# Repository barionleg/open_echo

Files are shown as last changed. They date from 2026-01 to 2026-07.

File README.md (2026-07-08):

links uPpdated by [barionleg](https://github.com/barionleg/) @20260708, to make them viewble online 

Open Echo Cover

## Universal Open-Source SONAR Controller and Development Stack

An ongoing open-source hardware and software project for building sonar systems for testing, boating, bathymetry, and research.  
The most commonly used hardware is the [TUSS4470 Arduino Shield](https://github.com/barionleg/open_echo/TUSS4470_shield_002/), which stacks on top of an Arduino Uno to drive the TUSS4470 ultrasonic driver.  
The board can run the [RAW Data Firmware](https://github.com/barionleg/open_echo/TUSS4470_shield_002/getting_started_TUSS4470_firmware.md) to operate a wide variety of ultrasonic transducers, covering frequencies from 40 kHz up to 1000 kHz in different media such as air or water.  

The [NMEA Output Firmware](https://github.com/barionleg/open_echo/TUSS4470_shield_002/arduino/NMEA_DBT_OUT/NMEA_DBT_OUT.ino) can read depth data from commercially available in-water ultrasonic transducers (e.g., on boats) and output NMEA0183-compatible data to a computer or a UART-connected device such as a Pixhawk or other controllers.  

Open Echo has been tested on multiple ultrasonic transducers and is compatible with all of them—from car parking sensors to Lowrance Tripleshot side-scan transducers.  

The [Python Interface Software](https://github.com/barionleg/open_echo/TUSS4470_shield_002/getting_started_interface.md) connects to Open Echo boards running the [RAW Data Firmware](https://github.com/barionleg/open_echo/TUSS4470_shield_002/getting_started_TUSS4470_firmware.md). It can display raw echo data, change configurations, output a TCP depth data stream, and more.  

Check the [Getting Started Guide](https://github.com/barionleg/open_echo/TUSS4470_shield_002/README.md)!  

If something is unclear or you find a bug, please open an issue.  

Raw Data Waterfall chart in the Python Desktop software:  
Open Echo Interface Software

## Getting the Hardware

If you need the hardware, you can order it using the [Hardware Files](https://github.com/barionleg/open_echo/TUSS4470_shield_002/TUSS4470_shield_hardware/TUSS4470_shield) from a board + SMT house ([JLC recommended](https://jlcpcb.com/?from=Neumi)).

They can also be bought as a complete and tested set direclty from Elecrow: https://www.elecrow.com/open-echo-tuss4470-development-shield.html

If they’re out of stock, or if you’d prefer to order them within Germany to reduce shipping costs, please send me an email at: openechoes@gmail.com

All profits go directly toward supporting and advancing the Open Echo project!

<b>If you don't order the boards directly from me or Elecrow, please be aware that I can't provide support.</b>

[TUSS4470 Arduino Shield](https://github.com/barionleg/open_echo/TUSS4470_shield_002/):  
PCB overview TUSS4470

### This project is currently in development. The [TUSS4470 Development Shield](TUSS4470_shield_002/) is ready for external use!  
Development is ongoing! Check the documentation and Discord channel for the latest updates.  

Want to stay updated or participate? Join the [Discord](https://discord.com/invite/rerCyqAcrw)!  

Check the [Getting Started Guide](https://github.com/barionleg/open_echo/TUSS4470_shield_002/README.md).  

## Vision
An accessible Open Source SONAR stack for development, research and real use:
- Open Source SONAR technology for differernt use cases
- support for a variety of commercial or DIY transducers in water and air
- relatively simple hardware that can be ordered from a board house
- easy entry for less experienced users
- community for exchange and development
- development of more advanced SONAR applications

--------
## Current State
- Universal TUSS4470-based Arduino shield for testing ultrasonic transducers  
- Python interface software for raw data visualization, configuration, and TCP data output  
- Tested depth range of at least 50 m in water  
- NMEA0183 compatible (DBT data output to other devices)  
- New all-in-one boards with STM32, TUSS4470, and boost converter currently in development
- picoW implementation in development (already successfull)
- UDP network RAW data transfer from picoW to Python interface running

--------
## Progress

The new (May 2025) [TUSS4470 Arduino Shield](https://github.com/barionleg/open_echo/TUSS4470_shield_002/) supports transducers from 40 kHz to 1000 kHz. It can drive them, receive echoes, filter signals, and send raw echo data to the Python backend.  
Driver voltage can be supplied from Arduino VIN or via the external XT30 connector. With an MT3608 boost converter, USB can be used as a power supply and boosted to the desired drive voltage (manual soldering required).  

The [TUSS4470 Arduino Shield](https://github.com/barionleg/open_echo/TUSS4470_shield_002/) is and will remain the main development board for this project. It is an excellent platform for testing and development.  
It can drive a wide range of transducers at different voltages, but it is limited by RAM size and sampling speed. You can capture 1800 samples at 12 microseconds per sample (~18 m range in water) with 8-bit resolution. For longer ranges, you can add a delay to capture echoes from more distant objects.  
This makes it a perfect board for learning, testing, and prototyping. Most software development is done using this board.  

For special use cases, additional boards and software are under development. 
Check the [development](https://github.com/barionleg/open_echo/development) folder for development work.

--------
## Open Echo Interface Software

Firmware examples are available in each project folder.  
The [**Open Echo Interface Software**](https://github.com/barionleg/open_echo/TUSS4470_shield_002/echo_interface.py) allows you to control Open Echo boards, view live data, and adjust board settings.  

Live echogram in water on Python software (6x speed):  
Software running with live echo data

## Test results Baltic Sea
Tested using a built-in 150 kHz SEAFARER transducer, powered at 15-20 V via an MT3608 boost converter from USB. In the plots, data capture begins at the bottom.

<table>
  <tr>
    <td align="center">
      38m Range<br/>
      <sub><b>38 m range test</b></sub>
    </td>
    <td align="center">
      Kiel Channel<br/>
      <sub><b>Kiel Channel sand and mud</b></sub>
    </td>
    <td align="center">
      Stollergrund<br/>
      <sub><b>Slope near Stollergrund</b></sub>
    </td>
  </tr>
  <tr>
    <td align="center">
      Stones and Sand<br/>
      <sub><b>Stones and sandy seabed</b></sub>
    </td>
    <td align="center">
      Fish<br/>
      <sub><b>Fish detection</b></sub>
    </td>
    <td align="center">
      Multiple Reflections<br/>
      <sub><b>Multiple reflections and seaweed</b></sub>
    </td>
  </tr>
  
</table>

## Videos

LINK TO LATEST VIDEO (https://www.youtube.com/watch?v=XF7rNGt6UYA)

https://www.youtube.com/watch?v=R3_NO2F7PsI  
https://www.youtube.com/watch?v=msbLVsY8xhQ  
https://www.youtube.com/watch?v=eJ8jVEQSx_Y  
https://www.youtube.com/watch?v=Bxh3rWd5RZk  
https://www.youtube.com/watch?v=UDYWQIizN7A  

## Useful Links
https://www.rapp-instruments.de/RemoteSensing/Roves/sidescan/sidescan.htm  
https://www.youtube.com/watch?v=ZtUkt8Q4EJE  

## Transducers: 

| Transducer Name | Ranking | Description | Frequency | Range Air/Water |  Price | Link |
|---|---|---|---|---|---|---|
| NASA / Seafarer 150kHz Echo Sounder | ⭐ ⭐ ⭐ | NASA in-hull boat transducer for echo sounding and simple fish-finding | 150kHz | >2m/>50m | 50-100€ | https://www.nasamarine.com/product/depth-transducer-with-7-metre-cable/7 
| Raymarine CPT-S |  ⭐ ⭐ ⭐ | High quality In-hull transducer with two frequencies | 50 + 200kHz | 2m/>50m | 200€ | https://www.raymarine.com/de-de/unsere-produkte/fischfinder-und-sonarmodule/fischfindergeber/cpt-s-durchbruchgeber |
| Lowrance Tripleshot Sidescan | ⭐ ⭐ ⭐ | Sidescan transducer with three FANS + temperature + down-scan | 200 + 455 + 600kHz | 0m/>20m | 200€ | https://www.echolotzentrum.de/shop/lowrance-tripleshot-heckgeber/ |
| Cheap Bathymetry 200kHz | ⭐ ⭐ ⭐ | good range, good price/performance, hard to order | 200kHz | 2m/>30m | 25€ | https://www.alibaba.com/product-detail/Range-customization-lakes-river-surveys-no_1600829423846.html |
| Cheap Car Parking Sensor | ⭐ ⭐ | Great for air, also works in water (not recommended) | 40kHz | >7m/>30m | 5€ | https://de.aliexpress.com/item/1005006546490802.html |
| Water flow sensor transducer | ⭐ ⭐ | Cheap and works in Air and Water. Very narrow beam in Water (about 5°)! | 1000kHz | 0.25m/>10m | 16€ for 5pcs | https://de.aliexpress.com/item/32818381566.html |
| Only for air 200 kHz | ⭐ | has a sinter glass matching layer, should only be used in air | 200kHz | 0.8m/(>8m) | 10€ | https://de.aliexpress.com/item/1005006007865920.html |
| Different Encapsualated Transducers | ⭐| Can be used for short range testing at higher frequencies | 200,300,400kHz | ?m/?m | 9-18€ | https://de.aliexpress.com/item/4000389134890.html |
| Very small PZT only | ⭐ | Only for testing / experimentation | 200kHz | 0.2m/?m | 10€ | https://de.aliexpress.com/item/1005007032482539.html |

> [!Note]
> The range values were measured using the TUSS4470 shield and Arduino Uno with an MT3608 boost converter set to 20 V for vDRV, so consider them approximate.

> [!Tip]
> As a general rule of thumb, lower frequencies propagate farther, while higher frequencies produce narrower beams and more detailed echoes.
>
> If you need a transducer for bathymetry, choose one of the first four options. Most commercial marine-grade (boating) transducers are also suitable, as long as they operate in the 40-1000 kHz range.

# Big Thanks for Your Support!
www.kogger.tech

## to the awesome project contributors:
Check this Cheap Yellow Display implementation out: https://github.com/matztam/open_echo_cyd_display
  
And all the great stuff JohnCHarrington contributed: https://github.com/JohnCHarrington/open_echo

## Star History

Star History Chart (https://www.star-history.com/#Neumi/open_echo&type=date&legend=top-left)

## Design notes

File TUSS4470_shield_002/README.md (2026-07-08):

# Open Echo TUSS4470 Shield Getting Started Guide

The TUSS4470 is an ultrasonic driver and receiver IC designed for seamless interaction with ultrasonic transducers. The TUSS4470 Arduino Shield is a development board that enables quick evaluation of the TUSS4470's features using the Arduino UNO platform.

### Overview
This repository provides a quick-start guide and example Arduino sketches for experimenting with Time-of-Flight (ToF) applications using the TUSS4470. The shield is ideal for development, testing, and prototyping, but is not intended as a finished consumer product.

### Getting Started
Connect the shield to an Arduino UNO.

Upload one of the provided example sketches to explore different features of the TUSS4470.

Use the Python software to see the echoes.

### Ordering
The shield can be easily ordered via [JLCPCB](https://jlcpcb.com/?from=Neumi) or other PCB fabrication services.

TUSS4470 schematic

> [!Note]
> I just got a few new boards, I sell as starter kits. Feel free to DM me on [Discord](https://discord.com/invite/rerCyqAcrw) if you're interested. Or send an email to: openechoes@gmail.com One assmebled board is 50€ + shipping. (10/2025)

PCB overview TUSS4470

## Electrical Connections
The TUSS4470 Shield is designed specifically for use with the Arduino UNO. It is not software- or pin-compatible with other Arduino boards at this time.

### Pin Connections
The shield interfaces with the Arduino UNO the following:
- SPI interface
- Four digital GPIOs
- Analog pin A0

### cINN and cFLT Filtering Capacitor Selection for Transducer Frequency
To support different ultrasonic transducers and their respective drive frequencies, the board provides preset capacitor options for <b/>40, 150, 200 (and 600) kHz</b>.

> [!Important]
> Use the onboard jumpers to select the appropriate cINN and cFLT values.

### Custom Capacitor Configuration
If you need to drive transducers at frequencies other than the provided presets and combinations (40 kHz, 150 kHz, 200 (and 600) kHz), you can customize the capacitor values:
- Desolder the default "CUSTOM" capacitors. (for cINN and cFLT)
- Solder your own calculated capacitor values onto the "CUSTOM" pads.

> [!TIP]
> Capacitors can be combined in parallel to achieve intermediate values.
> For example, to support 150 kHz, both the 200 kHz and CUSTOM capacitors are used in parallel to produce the required total capacitance.
> On board version 002, "Custom" is pre-selected to match the right capacitances <b/>together</b> with the 200kHz capacitors for 150kHz. 

Below is the electrical connection layout for the cINN and cFLT capacitors and jumpers:
TUSS4470 schematic

### Power Supply Options
The board supports two power input options:
- VIN (Arduino VIN pin):
Use this when the transducer operates at 12V max, as the Arduino cannot tolerate higher voltages.

- XT30 Connector:
Use this if you require higher voltage (up to 28V max) for more powerful transducers.

- MT3608 Boost Converter:
You can add an MT3608 boost converter to your board to generate a higher vDRV from the USB 5V supply. This solution is reliable and works well in many applications, such as powering marine transducers.
Simply take the MT3608 module (included in the starter kits), secure it to the shield with double-sided tape, and connect the three wires as shown:
TUSS4470 schematic

> [!Tip]
> To get started, use a 12V power supply. Many ultrasonic transducers operate reliably at this voltage.
> 
> Lower voltages may not adequately excite the transducer, resulting in weak or no echo signals.
> 
> The MT3608 should not be turned much further than 22V, as it becomes unstable.

> [!Warning]
> Do not exceed 28V input. Higher voltages can damage the board or components. Ensure proper polarity!

### Transducer Connection
Connect your PZT crystal or preassembled ultrasonic transducer to the "Transducer" header:

- Top pin: Ground (GND) / Shield
- Bottom pin: Signal

> [!Important]
> Proper polarity is crucial to minimize electrical noise and ensure optimal performance.
> For transducer connections exceeding 10 cm in length, use coaxial cable. Connect the cable shield to the transducer ground (GND).

The recommended setup is illustrated below:
TUSS4470 Board ready to use

> [!Important]
> Always connect GND/Shield to the TOP pin on the transducer.
> Using the wrong pin increases powerline noise and significantly weakens the signal.

Below: Comparison of a transducer wired incorrectly (left half) vs. correctly (right half).
Powerline noise on transducer cable shield

<b/>Next Steps: Proceed to [Getting Started with Arduino TUSS4470 Firmware](getting_started_TUSS4470_firmware.md).</b>

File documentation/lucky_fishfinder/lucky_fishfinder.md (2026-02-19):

---
layout: default
title: Lucky Fishfinder
nav_order: 9
---

# open_echo

Reverse engineering of the LUCKY fishfinder to learn about ultrasonics projects from a real product.

Using a trigger and analog pin on an Arduino UNO we can read RAW echo data from the LUCKY fishfinder product.

As of today, there are at least three hardware versions of the LUCKY fishfinder. All of them seem to follow a similar concept, but the pinout is different!

LUCKY fishfinder pins:
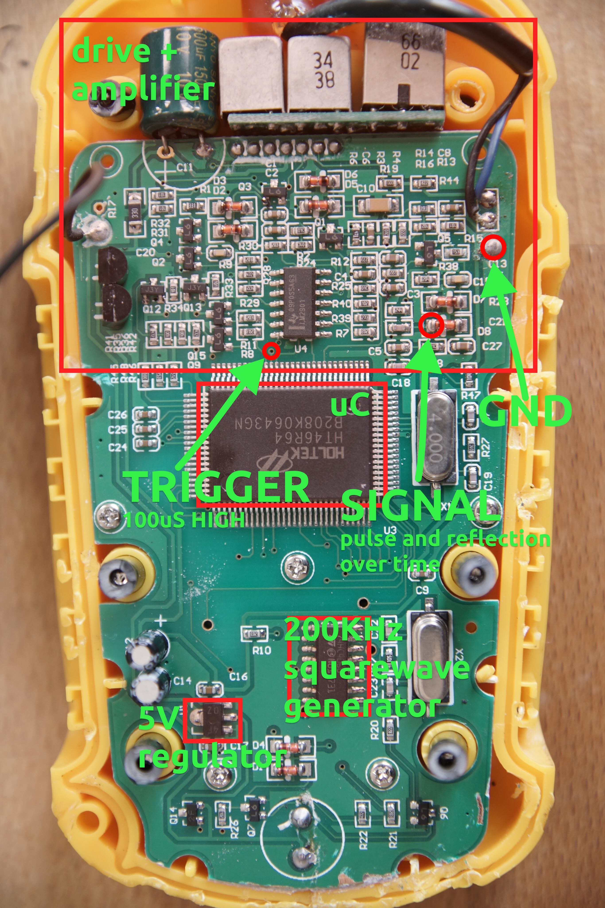
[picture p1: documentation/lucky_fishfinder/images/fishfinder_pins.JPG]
LUCKY fishfinder pin hack


Measured results using LUCKY fishfinder, FastLOGIC (Arduino) and Matplotlib + Python:
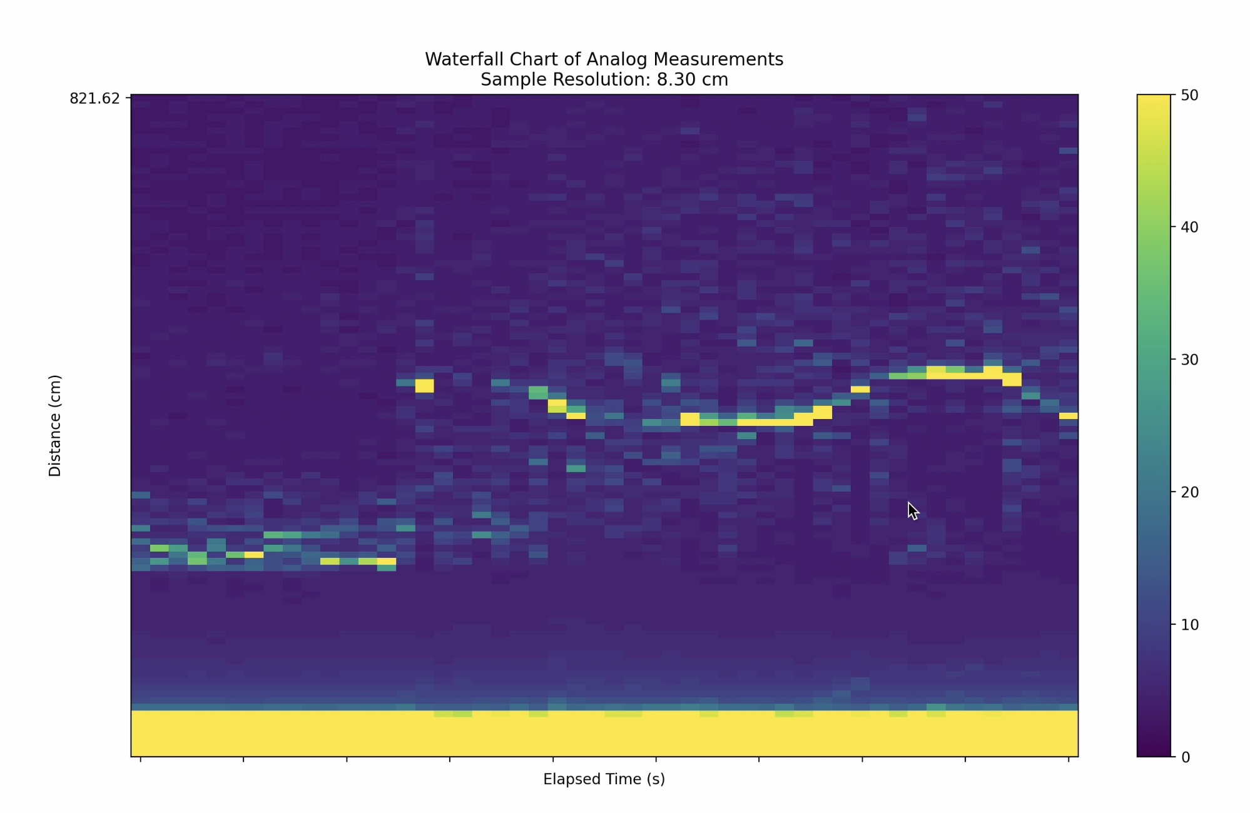
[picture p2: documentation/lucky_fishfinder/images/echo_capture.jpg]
LUCKY fishfinder pin hack


The chart shows a measurement of reflection time (translated to cm using 1482m/s speed of sound in water) and the past 50 measurements. The LUCKY fish finder takes around 2.3 full measurements per second. The brigter the pixel, the stronger the return signal. The plot shows the sandy ground in the first 1/4 and the rest is the reflection of a metal ladder in the water (horizontal).

# More info in this video:
LINK TO VIDEO (https://www.youtube.com/watch?v=UDYWQIizN7A)

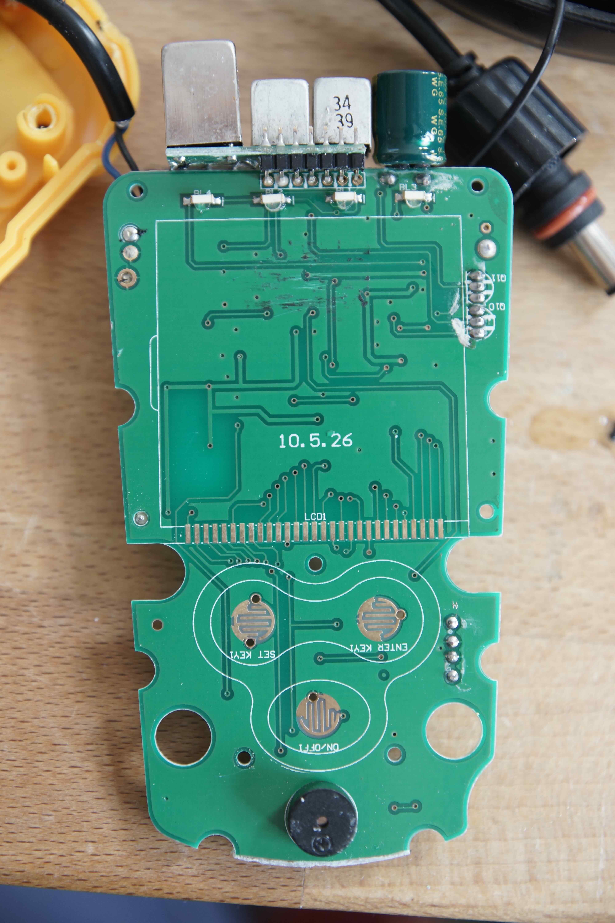
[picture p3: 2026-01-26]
documentation/lucky_fishfinder/images/back.JPG

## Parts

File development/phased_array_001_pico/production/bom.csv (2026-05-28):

Designator | Footprint | Quantity | Value | LCSC Part #
A1 | RaspberryPi_Pico_Common_Unspecified | 1 | RaspberryPi_Pico_W
C10, C11, C16, C17, C18, C19, C8, C9 | 0603 | 8 | 1uF | C15849
C12, C13, C14, C15 | 0603 | 4 | 100nF | C1525
C3 | 0603 | 1 | 10uF | C19702
J2 | PinHeader_1x03_P2.54mm_Vertical | 1 | OUT_SELECT
J3 | PinHeader_1x01_P2.54mm_Vertical | 1 | MT3608_OUT
J4 | PinHeader_1x01_P2.54mm_Vertical | 1 | MT3608_IN
J5, J6 | PinHeader_1x01_P2.54mm_Vertical | 2 | MT3608_GND
J7 | PinHeader_1x03_P2.54mm_Vertical | 1 | BOOST_ENABLE
MK1, MK2, MK3, MK4, MK5, MK6, MK7, MK8 | JST_EH_S2B-EH_1x02_P2.50mm_Horizontal | 8 | Microphone_Crystal
MK9 | JST_EH_S2B-EH_1x02_P2.50mm_Horizontal | 1 | Transducer_TX
Q1 | SOT-23 | 1 | MMBT2222A | C8512
R1, R10, R14, R18, R2, R22, R26, R30, R34, R6 | 0603 | 10 | 10k | C25804
R11, R12, R13, R15, R16, R5, R7, R8, R9 | 0603 | 9 | 1k | C21190
R17, R21, R25, R29, R33, R35, R36, R37 | 0603 | 8 | 100k | C25803
R19, R23, R27, R31, R38, R39, R40, R41 | 0603 | 8 | 1M | C22935
TP1 | TestPoint_Loop_D2.54mm_Drill1.5mm_Beaded | 1 | U_TRIGG
TP2 | TestPoint_Loop_D2.54mm_Drill1.5mm_Beaded | 1 | GND
U1, U3 | SOIC-14_3.9x8.7mm_P1.27mm | 2 | LM339 | C7948
U2, U5 | SOIC-14_3.9x8.7mm_P1.27mm | 2 | MCP6004 | C7378

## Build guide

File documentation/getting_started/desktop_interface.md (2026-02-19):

---
layout: default
title: Desktop Interface
parent: Getting Started
nav_order: 3
---

# Getting Started Open Echo Interface Software

The ***Open Echo Interface*** is a cross-platform Python application that interacts with the Arduino + TUSS4470 Shield. 
It displays ultrasonic echo data in real-time using a waterfall chart visualization. 
The application is intended primarily as a testing and development tool, but is stable enough for continuous use -tested for several days on a Raspberry Pi 4 without issues.

### Key Features
- Connects to Open Echo hardware over serial or UDP
- Displays real-time and historical data in a waterfall chart
- Auto-gain to adjust the waterfall chart colors
- Shows detected depth, and (if supported) temperature and drive voltage (`vDRV`)

> **Note**  
> This interface is primarily intended for development and testing. It's proven stable, but not yet a polished end-user application.

---

## Installation & Setup

### 1. Install openecho
```bash
pip install open-echo
```

### 2. Start Open Echo Interface Software
Run the following command to start the web server. 
```bash
openecho desktop
```

Select the correct COM port, then click Connect or press c on your keyboard. Once connected, the Open Echo board will begin streaming data, which will appear on the right side of the interface.
The red horizontal line indicates the currently detected depth, based on the strongest first echo received after the ring-down delay.

Open Echo Interface Software

### 4. Change to your own needs

You can change different settings in the first lines of the [**Open Echo Interface**](https://github.com/neumi/open_echo/tree/main/python/src/open_echo/desktop.py) code to customize it to your specific use cases.

### 📊 Parameter Settings

| Parameter | Description |
|---|---|
| `BAUD_RATE` | Must match the baud rate configured in the Arduino firmware. |
| `NUM_SAMPLES` | Must match the `NUM_SAMPLES` value used in the Arduino firmware. Can be overriden in the interface settings |
| `MAX_ROWS` | Sets the number of historical measurements displayed in the chart before it scrolls. |
| `Y_LABEL_DISTANCE`| Defines the vertical axis label spacing, in centimeters. |
| `SPEED_OF_SOUND`  | Used to convert sample timing into distance. Set to ~330 for air, ~1450 for water. Can be overriden in the interface settings|
| `SAMPLE_TIME` | Sampling interval in microseconds. For the Arduino UNO with [TUSS4470_arduino.ino](arduino/TUSS4470_arduino/TUSS4470_arduino.ino), this must be set to **13.2 µs**. Can be overriden in the interface settings|

--- 
Want to stay updated, have questions or want to participate? Join my [Discord](https://discord.com/invite/rerCyqAcrw)!

Or write an issue. Thanks!

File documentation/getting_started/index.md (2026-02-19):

---
layout: default
title: Getting Started
has_children: true
nav_order: 1
---

Getting started guides for Open Echo.

First, you will need an [Open Echo TUSS4470 Arduino Shield](TUSS4470_hardware.md).

This repository provides two software components to support the TUSS4470 Arduino Shield:
- [Arduino Firmware](TUSS4470_firmware.md) - Runs on an Arduino UNO board with the TUSS4470 shield and handles signal generation, echo capture, and communication.
- [Open Echo Interface](desktop_interface.md) - A desktop application that communicates with the Arduino, displays echo data as a real-time waterfall chart, and will soon allow runtime configuration of the system.

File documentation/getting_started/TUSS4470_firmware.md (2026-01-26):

---
layout: default
title: TUSS4470 Firmware
parent: Getting Started
nav_order: 2
---

# Getting Started with Arduino TUSS4470 Firmware

## Arduino Firmware
The Arduino firmware initializes the TUSS4470 device and manages the ultrasonic signal transmission and echo reception cycle. It sends digitized echo data over the serial interface to a host computer for analysis.

**Key Features**
- SPI communication with TUSS4470 chip
- Configurable drive frequency
- Adjustable sampling size (defines detection range)
- Basic bandpass filtering options
- Threshold detection for bottom line detection
- Binary data transfer to Python software

> [!NOTE]
> The firmware is designed to be easily modified. Users are encouraged to experiment with parameters to suit their needs.

## Uploading the Firmware
1. Open the Arduino IDE.
2. Select your Arduino UNO board and the correct COM port.
3. Set the configuration as described below.
4. Load the firmware sketch [TUSS4470_arduino.ino](https://github.com/neumi/open_echo/tree/main/TUSS4470_shield_002/arduino/TUSS4470_arduino/TUSS4470_arduino.ino).
5. Upload the sketch to the Arduino UNO.

## ⚙️ Configuration Parameters
Below are the key parameters used to control the ultrasonic transducer behavior, echo processing, filtering and outputs. `NUM_SAMPLES` must be kept in sync with the [Open Echo Interface](documentation/getting_started/desktop_interface.md). Due to RAM limitations on the Arduino UNO R3, it can't exceed ~1800 samples. The Arduino UNO R4 can reach ~12000 samples.

### 📊 Settings

| Parameter | Description |
|---|---|
| `NUM_SAMPLES` | Total number of ADC samples per measurement cycle. Must match the sample size used in visualization. Each sample is approximately **13.2 µs** long. |
| `BLINDZONE_SAMPLE_END` | Number of initial samples to ignore after sending the ultrasonic pulse. Avoids transducer ringdown echoes. |
| `THRESHOLD_VALUE` | Echo amplitude threshold for detecting the bottom. First echo stronger than this (after blind zone) is used. |

```cpp
#define NUM_SAMPLES 1800         // One frame of data at full sampling speed (~24 ms) -> in water ~18m -> in air ~4m
#define BLINDZONE_SAMPLE_END 200 // Ignore first 200 samples during early transducer ringdown
#define THRESHOLD_VALUE 0x19     // Echo strength threshold for bottom or obstacle detection
```

### 📡 Transducer Drive Frequency

The ultrasonic burst frequency is set by configuring **DRIVE_FREQUENCY**.
Enter the resonant frequency in Hz of your transducer. The TUSS4470 supports drive frequencies between 40 and 1000 kHz.

**Example Configuration:**
For **40 kHz**:  
```cpp
#define DRIVE_FREQUENCY 40000
```

#### 🔧 Alternative Frequencies

| Frequency | Notes |
|---|---|
| 40 kHz | Car parking sensor |
| 50 kHz | Raymarine CPT-S secondary frequency |
| 100 kHz | Chrhartz DIY transducer |
| 151 kHz | Muebau transducer |
| 200 kHz | Raymarine CPT-S |
| 216 kHz | Mini transducer |
| 230 kHz | 18mm transducer from AliExpress |
| 455 kHz | Lowrance Hook 3TS sidescan |
| 1000 kHz  | Water flow sensor transducer |

---

### 🎛️ Band-Pass Filter (TUSS4470)

To reduce noise and isolate the echo signals, a band-pass filter is configured on the **TUSS4470** IC. This should closely match the transducer’s drive frequency and the cFLT and cINN values on the board, see [Getting Started Guide](README.md#custom-capacitor-configuration).

**Example Configuration:**

```cpp
#define FILTER_FREQUENCY_REGISTER 0x00 // 40 kHz
```

#### 🧪 Other Filter Register Options

| Filter Register | Frequency | Notes |
|---|---|---|
| `0x00` | 40 kHz | Car parking sensor |
| `0x09` | 68 kHz | Secondary frequency [Raymarine CPT-S](https://www.raymarine.com/de-de/unsere-produkte/fischfinder-und-sonarmodule/fischfindergeber/cpt-s-durchbruchgeber)  |
| `0x10` | 100 kHz | Chrhartz transducer |
| `0x18` | 151 kHz | Muebau transducer |
| `0x1E` | 200 kHz | [Raymarine CPT-S](https://www.raymarine.com/de-de/unsere-produkte/fischfinder-und-sonarmodule/fischfindergeber/cpt-s-durchbruchgeber), [AliExpress 18mm](https://de.aliexpress.com/item/1005006007865920.html), [Alibaba](https://www.alibaba.com/product-detail/Range-customization-lakes-river-surveys-no_1600829423846.html) |

> 📖 For full configuration details, see the [TUSS4470 Datasheet – Table 7.1](https://www.ti.com/lit/ds/symlink/tuss4470.pdf).

### UDP Outputs (Arduino R4 Wifi Only)

If using the Arduino R4 Wifi, there is the option to output echoes and/or NMEA via UDP. Echo's output over UDP can be received by the python interface. NMEA depth output over UDP can be received by e.g. SignalK.

### Summary

To get started, upload the provided Arduino firmware [TUSS4470_arduino.ino](arduino/TUSS4470_arduino/TUSS4470_arduino.ino) to an Arduino UNO using the Arduino IDE. The firmware is preconfigured for a 40 kHz transducer (car parking sensor), which is ideal for first-time setup and testing. Once running, the Arduino continuously sends ultrasonic echo data over USB to the Open Echo Interface Python app for real-time visualization. You can customize parameters such as sample size, blind zone, detection threshold, drive frequency, and filter register to suit other transducers or application ranges. Just make sure NUM_SAMPLES matches in both the Arduino firmware and the Python interface. For most users, starting with the default 40 kHz setup provides the simplest and most reliable baseline.

<b/>Next Steps: Proceed to [Getting Started Open Echo Interface Software](getting_started_interface.md).</b>

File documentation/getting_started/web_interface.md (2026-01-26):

---
layout: default
title: Web Interface
parent: Getting Started
nav_order: 4
---

# Getting Started Open Echo Interface Software

The ***Open Echo Web Interface*** is a cross-platform Python application that interacts with the Arduino + TUSS4470 Shield. 
It displays ultrasonic echo data in real-time in the browser using a waterfall chart visualization. 
<!-- The application is intended primarily as a testing and development tool, but is stable enough for continuous use -tested for several days on a Raspberry Pi 4 without issues. -->

### Key Features
- Connects to Open Echo hardware over serial
- Displays real-time and historical data in a waterfall chart
<!-- - Auto-gain to adjust the waterfall chart colors -->
- Shows detected depth <!-- and (if supported) temperature and drive voltage (`vDRV`) -->
<!-- - Supports bidirectional communication for debugging and testing -->
- Shows depth at cursor on hover - useful for precise depths of non-ground echoes (fish!)

> **Note**  
> This interface is primarily intended for development and testing. It's proven stable, but not yet a polished end-user application.

---

## Installation & Setup

### 1. Install openecho
```bash
pip install open-echo
```

### 2. Start Open Echo Interface Software
Run the following command to start the web server. 
```bash
openecho web
```
Then go to http://localhost:8000. The first connection will be redirected to /config to set up the connection, then you should see your echoes.

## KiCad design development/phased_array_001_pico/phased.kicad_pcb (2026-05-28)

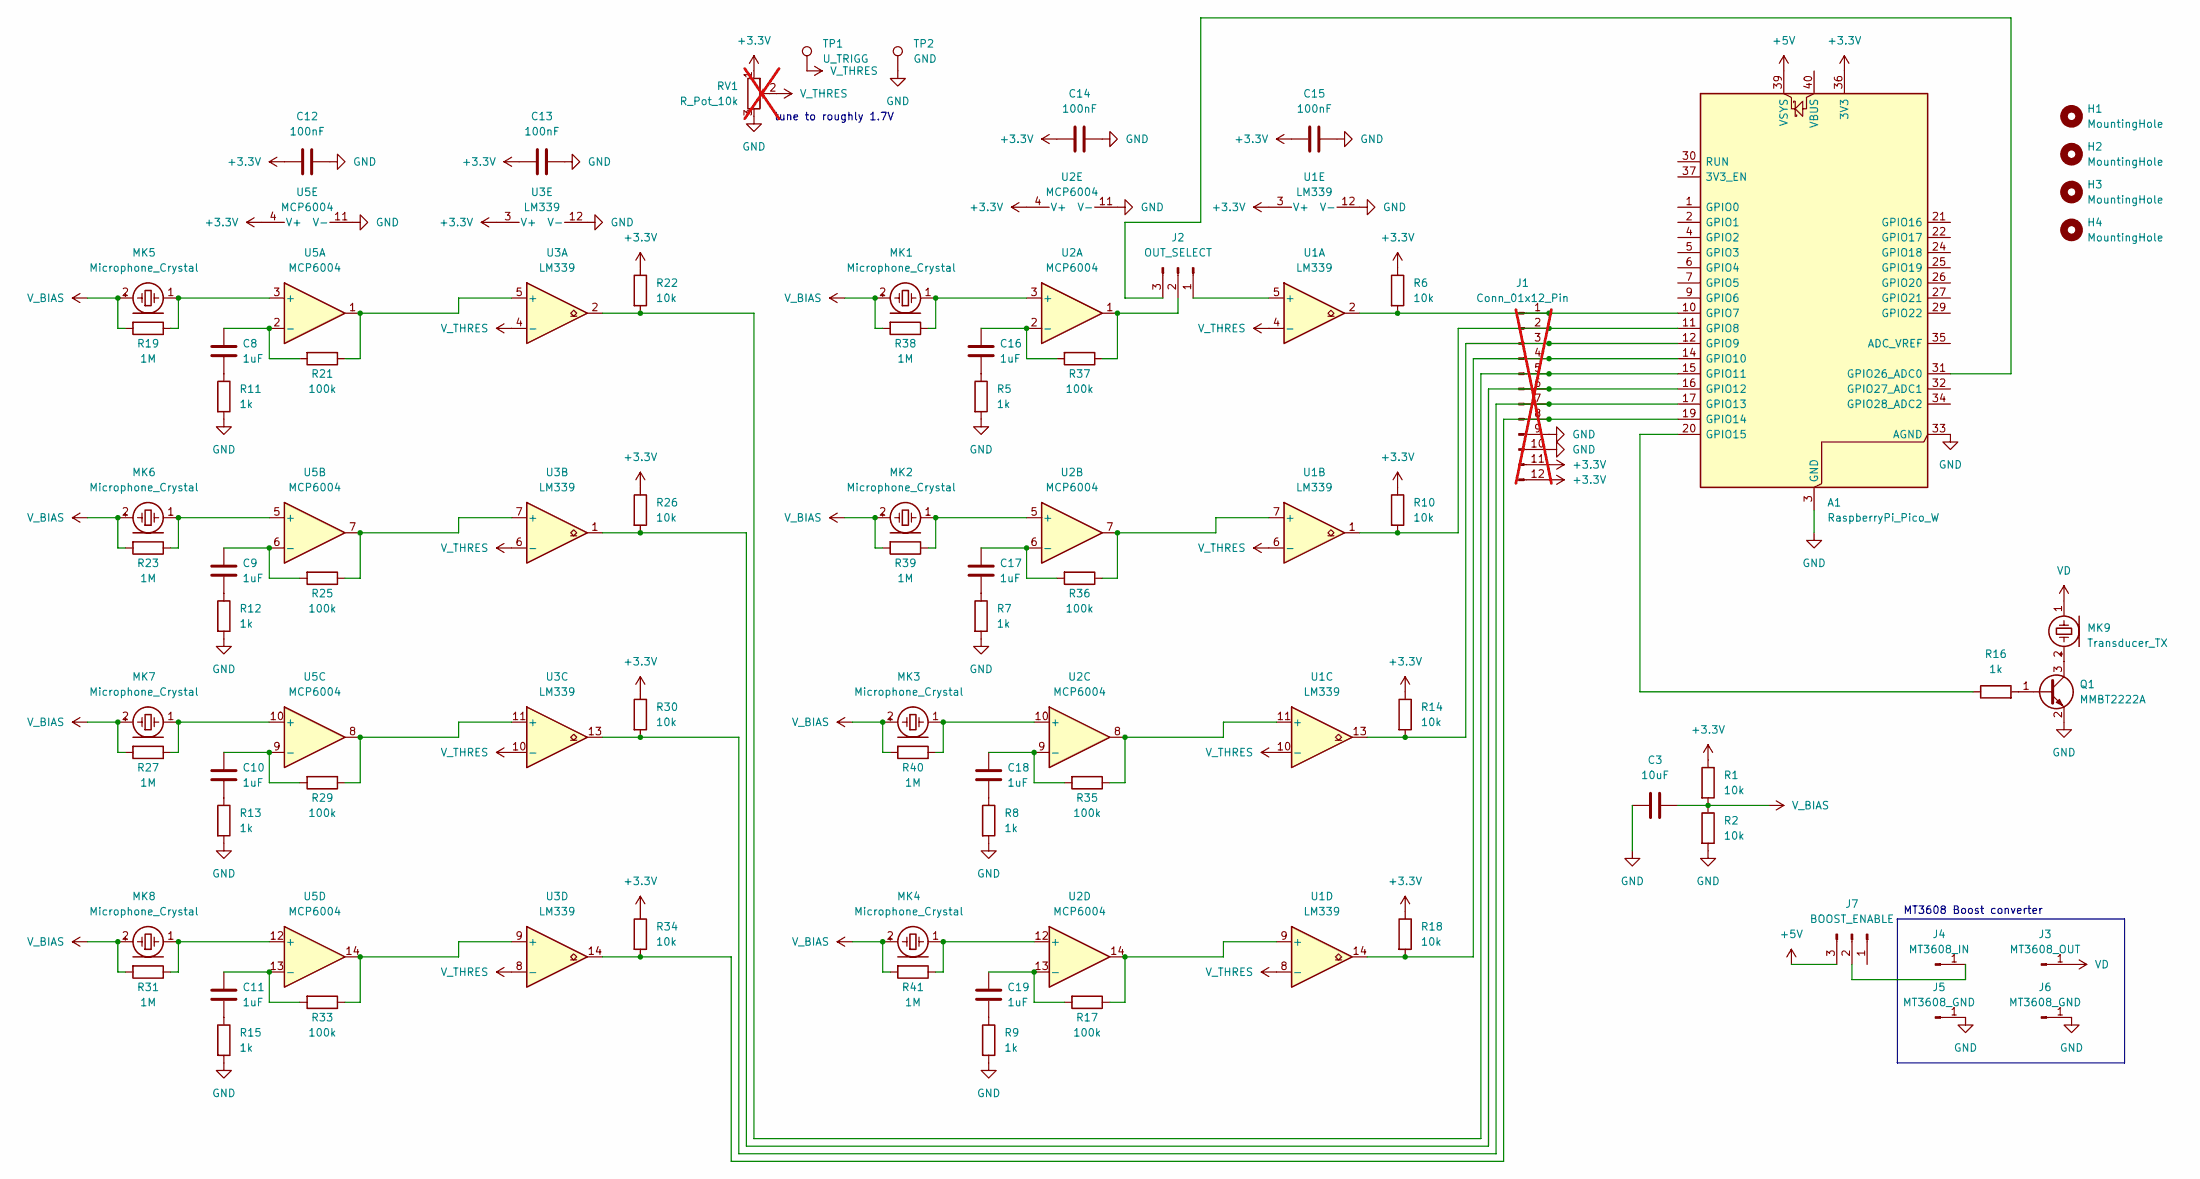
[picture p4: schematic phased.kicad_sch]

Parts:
A1: RaspberryPi_Pico_W; RaspberryPi_Pico_Common_Unspecified
C3: 10uF; C_0603_1608Metric; LCSC C19702
C8, C9, C10, C11, C16, C17, C18, C19: 1uF; C_0603_1608Metric; LCSC C15849
C12, C13, C14, C15: 100nF; C_0603_1608Metric; LCSC C1525
H1, H2, H3, H4: MountingHole; MountingHole_3.2mm_M3
J1: Conn_01x12_Pin; PinHeader_1x12_P2.54mm_Vertical; not fitted
J2: OUT_SELECT; PinHeader_1x03_P2.54mm_Vertical
J3: MT3608_OUT; PinHeader_1x01_P2.54mm_Vertical
J4: MT3608_IN; PinHeader_1x01_P2.54mm_Vertical
J5, J6: MT3608_GND; PinHeader_1x01_P2.54mm_Vertical
J7: BOOST_ENABLE; PinHeader_1x03_P2.54mm_Vertical
MK1, MK2, MK3, MK4, MK5, MK6, MK7, MK8: Microphone_Crystal; JST_EH_S2B-EH_1x02_P2.50mm_Horizontal
MK9: Transducer_TX; JST_EH_S2B-EH_1x02_P2.50mm_Horizontal
Q1: MMBT2222A; SOT-23; LCSC C8512
R1, R2, R6, R10, R14, R18, R22, R26, R30, R34: 10k; R_0603_1608Metric; LCSC C25804
R5, R7, R8, R9, R11, R12, R13, R15, R16: 1k; R_0603_1608Metric; LCSC C21190
R17, R21, R25, R29, R33, R35, R36, R37: 100k; R_0603_1608Metric; LCSC C25803
R19, R23, R27, R31, R38, R39, R40, R41: 1M; R_0603_1608Metric; LCSC C22935
RV1: R_Pot_10k; Potentiometer_Bourns_3296W_Vertical; not fitted
TP1: U_TRIGG; TestPoint_Loop_D2.54mm_Drill1.5mm_Beaded
TP2: GND; TestPoint_Loop_D2.54mm_Drill1.5mm_Beaded
U1, U3: LM339; SOIC-14_3.9x8.7mm_P1.27mm; LCSC C7948
U2, U5: MCP6004; SOIC-14_3.9x8.7mm_P1.27mm; LCSC C7378

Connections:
+3.3V: A1.36 (3V3), C12.1, C13.1, C14.1, C15.1, J1.11, J1.12, R1.1, R6.1, R10.1, R14.1, R18.1, R22.1, R26.1, R30.1, R34.1, RV1.1, U1.3 (V+), U2.4 (V+), U3.3 (V+), U5.4 (V+)
+5V: A1.39 (VSYS), J7.3
GND: A1.3 (GND), A1.8 (GND), A1.13 (GND), A1.18 (GND), A1.23 (GND), A1.28 (GND), A1.33 (AGND), A1.38 (GND), C3.2, C12.2, C13.2, C14.2, C15.2, J1.9, J1.10, J5.1 (Pin_1_1), J6.1 (Pin_1_1), Q1.2 (E), R2.2, R5.2, R7.2, R8.2, R9.2, R11.2, R12.2, R13.2, R15.2, RV1.3, TP2.1 (1_1), U1.12 (V-), U2.11 (V-), U3.12 (V-), U5.11 (V-)
unnamed: A1.10 (GPIO7), J1.1, R6.2, U1.2
unnamed: A1.11 (GPIO8), J1.2, R10.2, U1.1
unnamed: A1.12 (GPIO9), J1.3, R14.2, U1.13
unnamed: A1.14 (GPIO10), J1.4, R18.2, U1.14
unnamed: A1.15 (GPIO11), J1.5, R22.2, U3.2
unnamed: A1.16 (GPIO12), J1.6, R26.2, U3.1
unnamed: A1.17 (GPIO13), J1.7, R30.2, U3.13
unnamed: A1.19 (GPIO14), J1.8, R34.2, U3.14
unnamed: A1.20 (GPIO15), R16.1
unnamed: A1.31 (GPIO26_ADC0), J2.3
unnamed: C8.1, R11.1
unnamed: C9.1, R12.1
unnamed: C10.1, R13.1
unnamed: C11.1, R15.1
unnamed: C16.1, R5.1
unnamed: C17.1, R7.1
unnamed: C18.1, R8.1
unnamed: C19.1, R9.1
unnamed: J2.1, U1.5 (+)
unnamed: J2.2, R37.1, U2.1
unnamed: J4.1 (Pin_1_1), J7.2
unnamed: MK1.1 (-), R38.1, U2.3 (+)
unnamed: MK2.1 (-), R39.1, U2.5 (+)
unnamed: MK3.1 (-), R40.1, U2.10 (+)
unnamed: MK4.1 (-), R41.1, U2.12 (+)
unnamed: MK5.1 (-), R19.1, U5.3 (+)
unnamed: MK6.1 (-), R23.1, U5.5 (+)
unnamed: MK7.1 (-), R27.1, U5.10 (+)
unnamed: MK8.1 (-), R31.1, U5.12 (+)
unnamed: MK9.2 (+), Q1.3 (C)
unnamed: Q1.1 (B), R16.2
unnamed: R36.1, U1.7 (+), U2.7
unnamed: R35.1, U1.11 (+), U2.8
unnamed: R17.1, U1.9 (+), U2.14
unnamed: C16.2, R37.2, U2.2 (-)
unnamed: C17.2, R36.2, U2.6 (-)
unnamed: C18.2, R35.2, U2.9 (-)
unnamed: C19.2, R17.2, U2.13 (-)
unnamed: R21.1, U3.5 (+), U5.1
unnamed: R25.1, U3.7 (+), U5.7
unnamed: R29.1, U3.11 (+), U5.8
unnamed: R33.1, U3.9 (+), U5.14
unnamed: C8.2, R21.2, U5.2 (-)
unnamed: C9.2, R25.2, U5.6 (-)
unnamed: C10.2, R29.2, U5.9 (-)
unnamed: C11.2, R33.2, U5.13 (-)
VD: J3.1 (Pin_1_1), MK9.1 (-)
V_BIAS: C3.1, MK1.2 (+), MK2.2 (+), MK3.2 (+), MK4.2 (+), MK5.2 (+), MK6.2 (+), MK7.2 (+), MK8.2 (+), R1.2, R2.1, R19.2, R23.2, R27.2, R31.2, R38.2, R39.2, R40.2, R41.2
V_THRES: RV1.2, TP1.1 (1_1), U1.4 (-), U1.6 (-), U1.8 (-), U1.10 (-), U3.4 (-), U3.6 (-), U3.8 (-), U3.10 (-)

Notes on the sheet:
tune to roughly 1.7V
MT3608 Boost converter

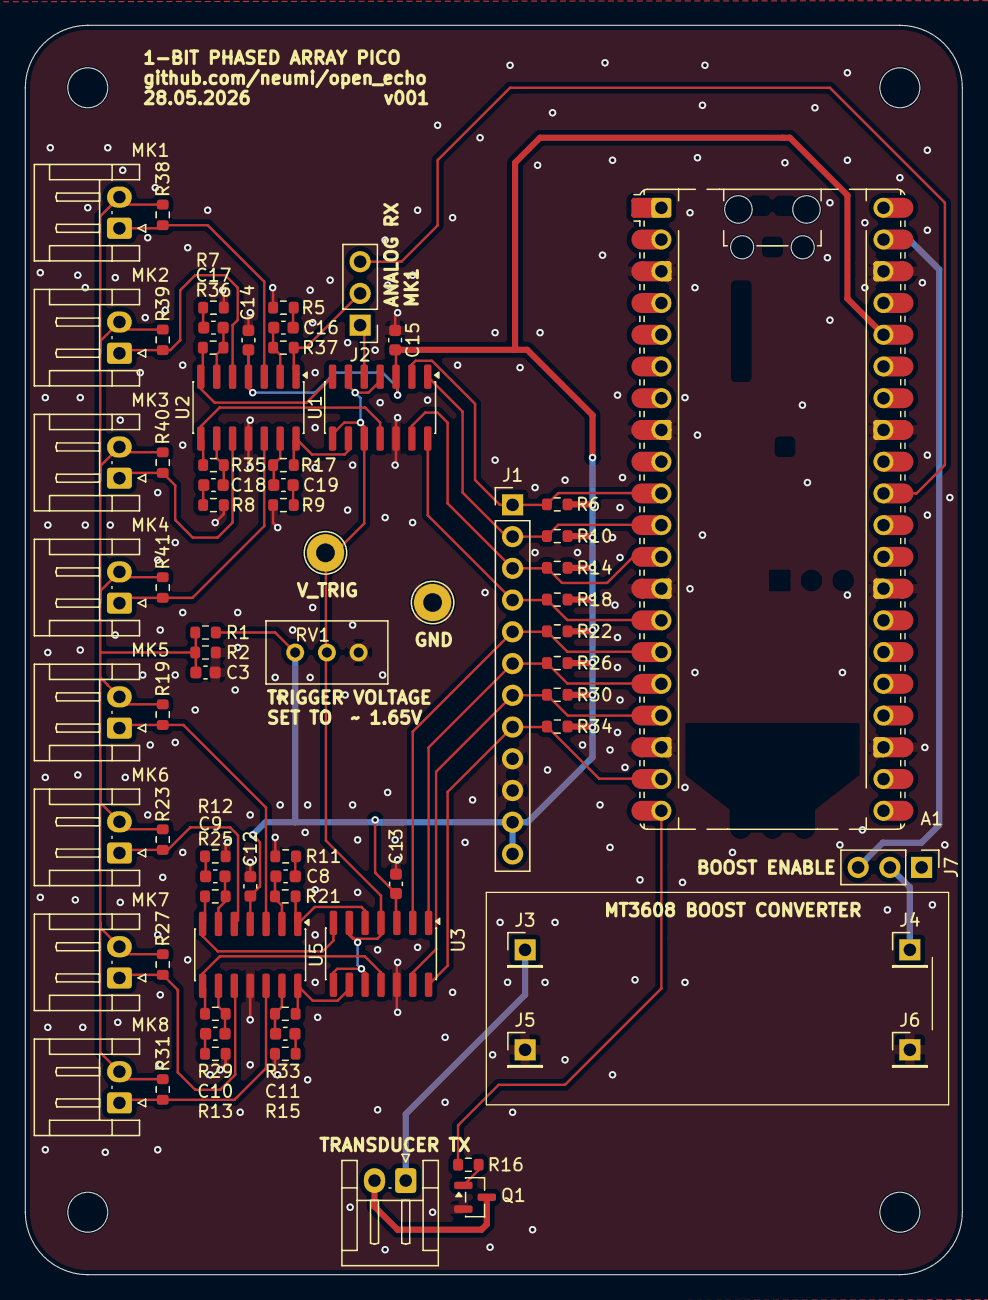
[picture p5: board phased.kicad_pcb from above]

Board: 2 copper layers, 75.0 x 100.0 mm, 77 parts (0 on the bottom side), 52 nets.

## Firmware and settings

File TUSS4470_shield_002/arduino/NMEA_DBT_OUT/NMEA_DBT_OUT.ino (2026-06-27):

#include <SPI.h>

// Pin configuration
const int SPI_CS = 10;
const int IO1 = 8;
const int IO2 = 9;
const int O3 = 3;
const int O4 = 2;
const int analogIn = A0;

// Number of ADC samples to take per measurement cycle
// Each sample takes approximately 13.2 microseconds
#define NUM_SAMPLES 5224 // samples/iterations each taking 13.2uS needed to cover 50m of water depth

// Number of initial samples to ignore after sending the transducer pulse
// These ignored samples represent the "blind zone" where the transducer is still ringing
#define BLINDZONE_SAMPLE_END 450

// Threshold level for detecting the bottom echo
// The first echo stronger than this value (after the blind zone) is considered the bottom
#define THRESHOLD_VALUE 0x1F


// ---------------------- DRIVE FREQUENCY SETTINGS ----------------------
// Sets the output frequency of the ultrasonic transducer by configuring Timer1
// Use the formula: DRIVE_FREQUENCY_TIMER_DIVIDER = (16000000 / (2 * desired_frequency)) - 1
// Example for 200 kHz: (16,000,000 / (2 * 200,000)) - 1 = 39
#define DRIVE_FREQUENCY_TIMER_DIVIDER 199 // 40 kHz (e.g., car parking sensor)
// #define DRIVE_FREQUENCY_TIMER_DIVIDER 52  // 151 kHz (Muebau transducer)
// #define DRIVE_FREQUENCY_TIMER_DIVIDER 39  // 200 kHz (Raymarine CPT-S transducer)
// #define DRIVE_FREQUENCY_TIMER_DIVIDER 36  // 216 kHz (mini transducer)
// #define DRIVE_FREQUENCY_TIMER_DIVIDER 34  // 230 kHz (18mm 200kHz transducer from AliExpress)



// ---------------------- BANDPASS FILTER SETTINGS ----------------------
// Sets the digital band-pass filter frequency on the TUSS4470 driver chip
// This should roughly match the transducer drive frequency
// For additional register values, see TUSS4470 datasheet, Table 7.1 (pages 17–18)
#define FILTER_FREQUENCY_REGISTER 0x00 // 40 kHz
// #define FILTER_FREQUENCY_REGISTER 0x10 // 100 kHz
// #define FILTER_FREQUENCY_REGISTER 0x18 // 151 kHz
// #define FILTER_FREQUENCY_REGISTER 0x1E // 200 kHz
// #define FILTER_FREQUENCY_REGISTER 0x20 // 230 kHz


byte misoBuf[2];  // SPI receive buffer
byte inByteArr[2];  // SPI transmit buffer

byte analogValues[NUM_SAMPLES];
volatile int pulseCount = 0;
volatile int sampleIndex = 0;

float temperature = 0.0f;
int vDrv = 0;

volatile bool detectedDepth = false;  // Condition flag
volatile int depthDetectSample = 0;


ISR(TIMER1_COMPA_vect)
{
  pulseCount++;
  if (pulseCount >= 32)
  {
    stopTransducer();
    pulseCount = 0;  // Reset counter for next cycle
  }
}

void startTransducerBurst()
{
  TCCR1A = _BV(COM1A0);  // Toggle OC1A (pin 9) on Compare Match
  TCCR1B = _BV(WGM12) | _BV(CS10);  // CTC mode, no prescaler

  OCR1A = DRIVE_FREQUENCY_TIMER_DIVIDER;

  TIMSK1 = _BV(OCIE1A);  // Enable Timer1 Compare Match A interrupt
}

void stopTransducer()
{
  TCCR1A = 0;
  TCCR1B = 0;  // Stop Timer1 by clearing clock select bits
  TIMSK1 = 0;  // Disable Timer1 interrupt
}

byte tuss4470Read(byte addr) {
  inByteArr[0] = 0x80 + ((addr & 0x3F) << 1);  // Set read bit and address
  inByteArr[1] = 0x00;  // Empty data byte
  inByteArr[0] |= tuss4470Parity(inByteArr);
  spiTransfer(inByteArr, sizeof(inByteArr));

  return misoBuf[1];
}

void tuss4470Write(byte addr, byte data) {
  inByteArr[0] = (addr & 0x3F) << 1;  // Set write bit and address
  inByteArr[1] = data;
  inByteArr[0] |= tuss4470Parity(inByteArr);
  spiTransfer(inByteArr, sizeof(inByteArr));
}

byte tuss4470Parity(byte* spi16Val) {
  return parity16(BitShiftCombine(spi16Val[0], spi16Val[1]));
}

void spiTransfer(byte* mosi, byte sizeOfArr) {
  memset(misoBuf, 0x00, sizeof(misoBuf));

  digitalWrite(SPI_CS, LOW);
  for (int i = 0; i < sizeOfArr; i++) {
    misoBuf[i] = SPI.transfer(mosi[i]);
  }
  digitalWrite(SPI_CS, HIGH);
}

unsigned int BitShiftCombine(unsigned char x_high, unsigned char x_low) {
  return (x_high << 8) | x_low;  // Combine high and low bytes
}

byte parity16(unsigned int val) {
  byte ones = 0;
  for (int i = 0; i < 16; i++) {
    if ((val >> i) & 1) {
      ones++;
    }
  }
  return (ones + 1) % 2;  // Odd parity calculation
}

void handleInterrupt() {
  if (!detectedDepth) {
    depthDetectSample = sampleIndex;
    detectedDepth = true;
  }
}

void setup()
{
  Serial.begin(9600);

  SPI.begin();
  SPI.setBitOrder(MSBFIRST);
  SPI.setClockDivider(SPI_CLOCK_DIV16);
  SPI.setDataMode(SPI_MODE1);  // CPOL=0, CPHA=1


  pinMode(SPI_CS, OUTPUT);
  digitalWrite(SPI_CS, HIGH);

  // Configure GPIOs
  pinMode(IO1, OUTPUT);
  digitalWrite(IO1, HIGH);
  pinMode(IO2, OUTPUT);
  pinMode(O4, INPUT_PULLUP);
  attachInterrupt(digitalPinToInterrupt(O4), handleInterrupt, RISING);

  // Initialize TUSS4470 with specific configurations
  // check TUSS4470 datasheet for more settings!
  tuss4470Write(0x10, FILTER_FREQUENCY_REGISTER);  // Set BPF center frequency
  tuss4470Write(0x16, 0xF);  // Enable VDRV (not Hi-Z)
  tuss4470Write(0x1A, 0x0F);  // Set burst pulses to 16
  tuss4470Write(0x17, THRESHOLD_VALUE); // enable threshold detection on OUT_4

  // Set up ADC
  ADCSRA = (1 << ADEN)  |  // Enable ADC
           (1 << ADPS2);   // Set prescaler to 16 (16 MHz / 16 = 1 MHz ADC clock)
  ADMUX = (1 << REFS0);    // Reference voltage: AVcc
  // Input channel: ADC0 (default)
  ADCSRB = 0;              // Free-running mode
  ADCSRA |= (1 << ADATE);  // Enable auto-trigger (free-running)
  ADCSRA |= (1 << ADSC);   // Start conversion
}

void loop()
{
  // Trigger time-of-flight measurement
  tuss4470Write(0x1B, 0x01);

  startTransducerBurst();

  //float startTime = micros();

  // Read analog values from A0
  sampleIndex = 0;
  for (sampleIndex = 0; sampleIndex < NUM_SAMPLES; sampleIndex++) {
    while (!(ADCSRA & (1 << ADIF))); // Wait for conversion to complete
    ADCSRA |= (1 << ADIF);           // Clear the interrupt flag
    // analogValues[sampleIndex] = ADC >> 2;           // Read ADC value
    if (sampleIndex == BLINDZONE_SAMPLE_END) {
      detectedDepth = false;
    }
  }
  //float runTime = micros() - startTime;

  // Stop time-of-flight measurement
  tuss4470Write(0x1B, 0x00);

  sendNmeaDBT();

  delay(250);
}


void sendNmeaDBT() {
  // Calculate depth in meters
  float time_of_flight = depthDetectSample * 13.0e-6f;
  float depth_m = (time_of_flight * 1450.0f) / 2.0f;

  float depth_ft = depth_m * 3.28084f;
  float depth_fa = depth_m / 1.8288f;

  // Convert floats to strings
  char str_ft[10], str_m[10], str_fa[10];
  dtostrf(depth_ft, 4, 1, str_ft);
  dtostrf(depth_m, 4, 1, str_m);
  dtostrf(depth_fa, 4, 1, str_fa);

  // Trim leading spaces (manually)
  char* ptr_ft = str_ft;
  char* ptr_m = str_m;
  char* ptr_fa = str_fa;
  while (*ptr_ft == ' ') ptr_ft++;
  while (*ptr_m == ' ') ptr_m++;
  while (*ptr_fa == ' ') ptr_fa++;

  // Build the NMEA sentence
  char sentence[80];
  snprintf(sentence, sizeof(sentence),
           "$SDDBT,%s,f,%s,M,%s,F", ptr_ft, ptr_m, ptr_fa);

  // Calculate checksum (XOR of chars between $ and *)
  uint8_t checksum = 0;
  for (int i = 1; sentence[i] != '\0'; i++) {
    checksum ^= sentence[i];
  }

  // Final output with checksum
  char fullSentence[90];
  snprintf(fullSentence, sizeof(fullSentence), "%s*%02X\r\n", sentence, checksum);

  Serial.print(fullSentence);
}

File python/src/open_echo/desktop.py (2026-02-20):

# Desktop client — connects to the web server's WebSocket for echo data.
# If no web server is running, spawns one as a subprocess.
import asyncio
import json
import logging
import subprocess
import sys
import threading

import numpy as np
import pyqtgraph as pg
import qdarktheme
from PyQt5.QtCore import QObject, Qt, pyqtSignal
from PyQt5.QtGui import QColor, QPalette
from PyQt5.QtWidgets import (
    QApplication,
    QCheckBox,
    QComboBox,
    QHBoxLayout,
    QLabel,
    QLineEdit,
    QMainWindow,
    QMessageBox,
    QPushButton,
    QVBoxLayout,
    QWidget,
)
from qasync import QEventLoop

log = logging.getLogger(__name__)

MAX_ROWS = 300  # Number of time steps (Y-axis)
Y_LABEL_DISTANCE = 50  # distance between labels in cm
DEFAULT_LEVELS = (0, 256)

# Default server URL
DEFAULT_SERVER_URL = "http://localhost:8000"


# ---------------------------------------------------------------------------
# WebSocket client — receives echo data from the web server
# ---------------------------------------------------------------------------


class WebSocketClient(QObject):
    """WebSocket client running in a background thread with its own event loop.

    qasync's event loop doesn't support TCP ``create_connection``, so we run
    the websockets client in a dedicated thread and bridge data back to Qt
    via pyqtSignal.
    """

    packet_received = pyqtSignal(dict)
    connection_changed = pyqtSignal(str)  # "connected", "reconnecting"

    def __init__(self, server_url: str = DEFAULT_SERVER_URL):
        super().__init__()
        self.server_url = server_url.rstrip("/")
        self._ws_url = (
            self.server_url.replace("http://", "ws://").replace(
                "https://", "wss://"
            )
            + "/ws"
        )
        self._thread: threading.Thread | None = None
        self._stop_event = threading.Event()

    def start(self):
        self._stop_event.clear()
        self._thread = threading.Thread(
            target=self._thread_main, daemon=True, name="ws-client"
        )
        self._thread.start()

    def stop(self):
        self._stop_event.set()
        if self._thread:
            self._thread.join(timeout=5)
            self._thread = None

    def _thread_main(self):
        """Entry point for the background thread — runs its own asyncio loop."""
        loop = asyncio.new_event_loop()
        asyncio.set_event_loop(loop)
        try:
            loop.run_until_complete(self._run())
        finally:
            loop.close()

    async def _run(self):
        import websockets

        retry_delay = 1.0
        while not self._stop_event.is_set():
            try:
                self.connection_changed.emit("reconnecting")
                async with websockets.connect(self._ws_url) as ws:
                    self.connection_changed.emit("connected")
                    retry_delay = 1.0
                    async for raw in ws:
                        if self._stop_event.is_set():
                            break
                        try:
                            data = json.loads(raw)
                            self.packet_received.emit(data)
                        except json.JSONDecodeError:
                            log.warning("Invalid JSON from WebSocket")
            except asyncio.CancelledError:
                break
            except Exception as e:
                log.warning(
                    "WebSocket error: %s — retrying in %.0fs", e, retry_delay
                )
                self.connection_changed.emit("reconnecting")
                # Use stop_event.wait so we can exit promptly
                if self._stop_event.wait(timeout=retry_delay):
                    break
                retry_delay = min(retry_delay * 2, 30.0)


# ---------------------------------------------------------------------------
# Web server lifecycle — auto-detect or spawn
# ---------------------------------------------------------------------------


class WebServerManager:
    """Checks for an existing web server and spawns one if needed."""

    def __init__(self, server_url: str = DEFAULT_SERVER_URL):
        self.server_url = server_url.rstrip("/")
        self._process: subprocess.Popen | None = None
        self._owned = False  # True if we spawned the server

    async def ensure_running(self) -> bool:
        """Return True once the server is reachable. Spawns if needed."""
        if await asyncio.get_event_loop().run_in_executor(
            None, self._is_reachable
        ):
            log.info("Web server already running at %s", self.server_url)
            return True

        log.info("No web server found — spawning one...")
        self._spawn()
        # Wait for it to become reachable
        for _ in range(60):  # up to ~30 s
            await asyncio.sleep(0.5)
            if await asyncio.get_event_loop().run_in_executor(
                None, self._is_reachable
            ):
                log.info("Web server is now reachable")
                return True

        log.error("Web server failed to start within timeout")
        return False

    def _is_reachable(self) -> bool:
        import urllib.request

        try:
            resp = urllib.request.urlopen(
                f"{self.server_url}/api/settings", timeout=2
            )
            return resp.status == 200
        except Exception:
            return False

    def _spawn(self):
        self._process = subprocess.Popen(
            [
                sys.executable,
                "-m",
                "uvicorn",
                "open_echo.web:app",
                "--host",
                "0.0.0.0",
                "--port",
                "8000",
            ],
            stdout=subprocess.DEVNULL,
            stderr=subprocess.DEVNULL,
        )
        self._owned = True

    def shutdown(self):
        if self._owned and self._process:
            log.info("Shutting down spawned web server (pid %d)", self._process.pid)
            self._process.terminate()
            try:
                self._process.wait(timeout=5)
            except subprocess.TimeoutExpired:
                self._process.kill()
                self._process.wait(timeout=2)
            self._process = None


# ---------------------------------------------------------------------------
# HTTP helpers — synchronous (run via executor from qasync loop)
# ---------------------------------------------------------------------------


def _fetch_settings_sync(server_url: str) -> dict | None:
    import json
    import urllib.request

    try:
        resp = urllib.request.urlopen(
            f"{server_url}/api/settings", timeout=5
        )
        return json.loads(resp.read())
    except Exception as e:
        log.error("Failed to fetch settings: %s", e)
        return None
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

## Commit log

2026-01-26 feat: Publish python package and docs site
    Move all files to new folder structure
    feat: combine echo readers
    chore: stylefix
    feat: Add CLI commands for desktop/web
    chore: Typing and ruff
    Readd deleted assets
    feat: Add tests
    chore: stylefixes
    chore: stylefixes again
    feat: Add github actions for python CICD
    feat: Add bump-my-version
    Bump version: 0.1.0 → 0.1.1
    feat: Use hatch-vcs
    Bump version: 0.1.1 → 0.1.2
    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
    [cli.py, depth_output.py, desktop.py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]
2026-02-19 Fix type hints for depth_callback and data_callback in EchoReader
    [web.py]
2026-02-19 Fix broadcast_json to handle per-connection send failures
    [web.py]
2026-02-19 Fix EchoReader to retry with backoff on exceptions instead of blocking
    [web.py]
2026-02-19 Integrate UDP relay code
2026-02-20 Remove a few more prints
2026-05-28 added phased array prototype
    [bom.csv, designators.csv, phased.kicad_pcb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]
